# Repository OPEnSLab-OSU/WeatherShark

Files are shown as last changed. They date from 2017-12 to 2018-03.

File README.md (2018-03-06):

# WeatherShark

Links via Fusion to CAD files to 3D print

Hanging rod: http://a360.co/2F3G7Bz

Crossbar: http://a360.co/2F3G7Bz

Bearing Hanger: http://a360.co/2EYjwWZ

Fiber Clamp: http://a360.co/2FCrSVv - the new version of this needs to be refined a bit to get a good latch on the fiber

Ventilator with Turbine Rod: http://a360.co/2EYo6IR

Body + Bottom Plate: http://a360.co/2EXwTed

Note: Currently missing in the documentation: the WeatherShark board should have a 100 kOhm resistor from the RTC INT Pin to VCC.

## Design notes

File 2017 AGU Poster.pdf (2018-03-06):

# WeatherShark

# A light-weight weather station to swim through the skies

# Alex J Krejci¹ , Jose Manuel Lopez Alcala

1

# , Mitch Nelke

1

# , James Wagner

1

# , Chet Udell

1

# , Chad W Higgins

1

# , John S Selker

1

## 1 Department of Biological & Ecological Engineering, Oregon State University

Future
- Sell device
- Uploaded data for public access
- Use data for research

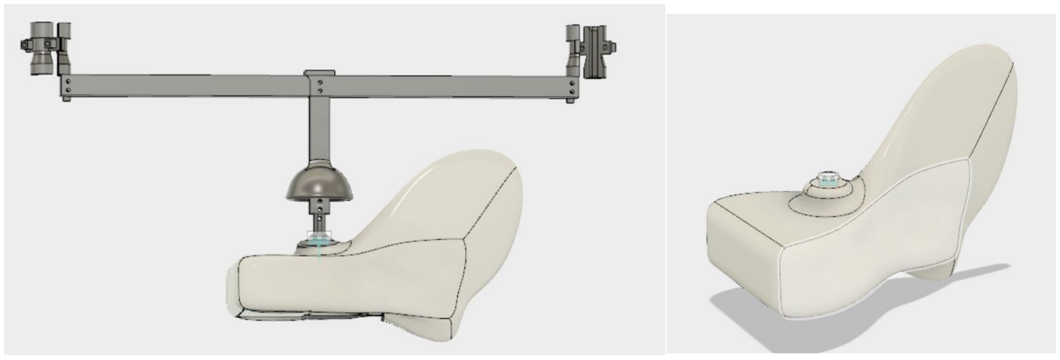
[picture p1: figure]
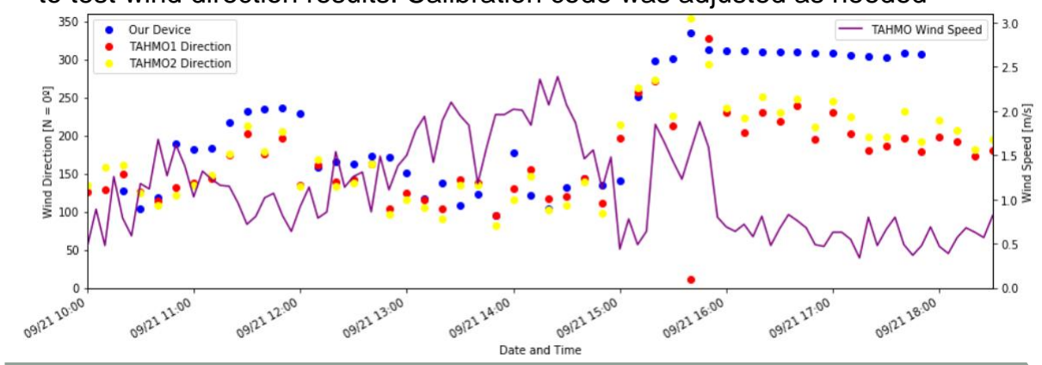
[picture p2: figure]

# Design Criteria

# Design Details – Version Gamma - Present

# Electronics

# Results – Version Beta - Past

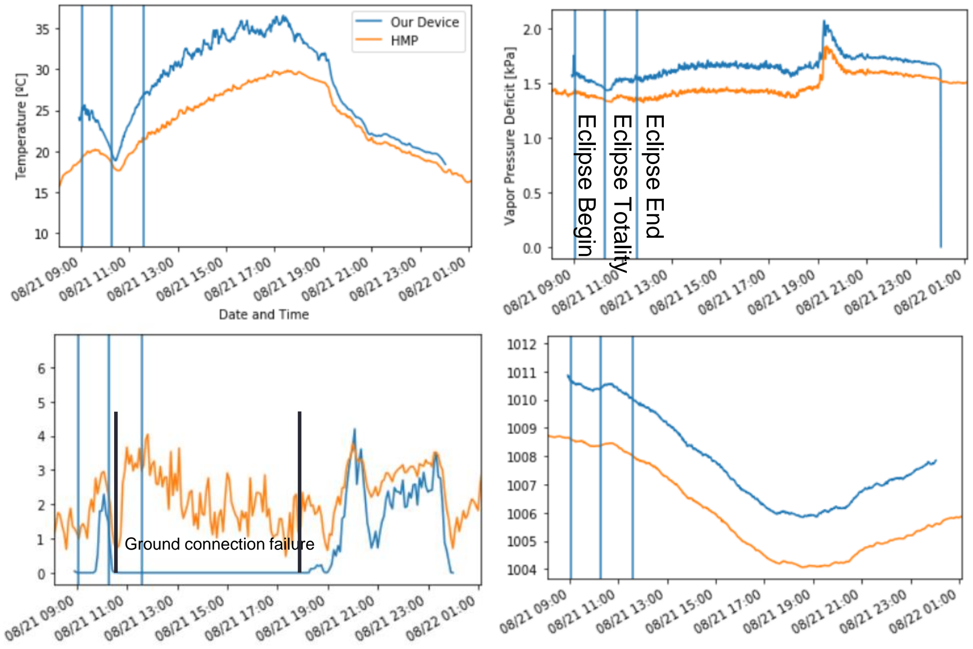
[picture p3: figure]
Eclipse End; Ground connection failure

Funding for this research was provided by NSF Earth Sciences division Instrumentation and Facilities program
The author would like to acknowledge the support of Jason Kelley, Hadi Al-Agele, and Thomas DeBell for useful discussions on design ideas.

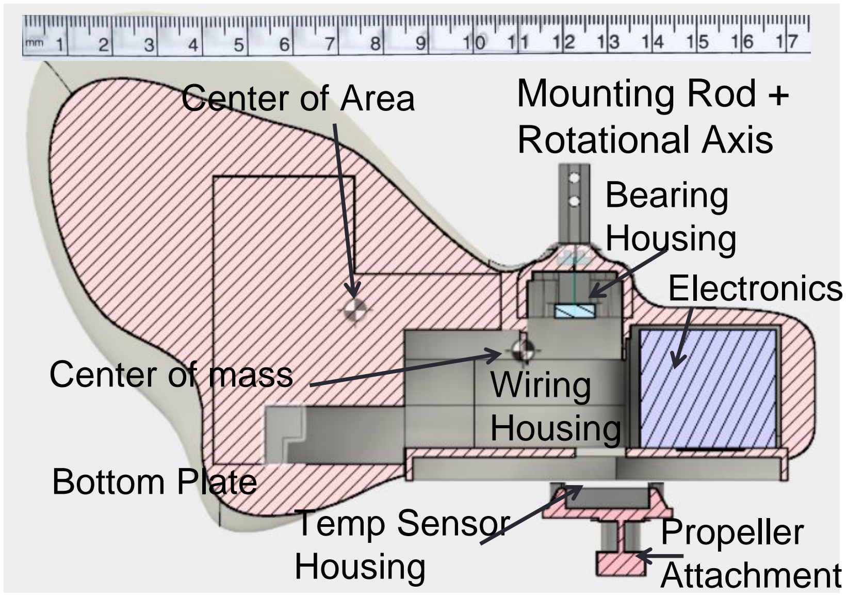
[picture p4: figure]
Electronics; Battery Compartment; Cross section of housing; Mounting Rod + Rotational Axis; Wiring Housing; Center of mass; Center of Area; Temp Sensor Housing; Propeller Attachment; Bearing Housing; Bottom Plate

# Version Gamma/Delta - Future

Beta
- Increased ventilation needed for temp sensor
- Wind direction at low speeds is poor – improve rotation capability Gamma
- Currently in testing phase – Beta problems are resolved
- Reliable sensor data should be available at this point
Delta
- Wireless communications, solar charging, and solar radiation sensing are a priority
- Rainfall - secondary objective.
Beyond
- Reduce form factor by building completely custom PCB
- Scalability using injection molding
- Retailing device for citizen science cloud data collection.

# ACKNOWLEDGMENTS

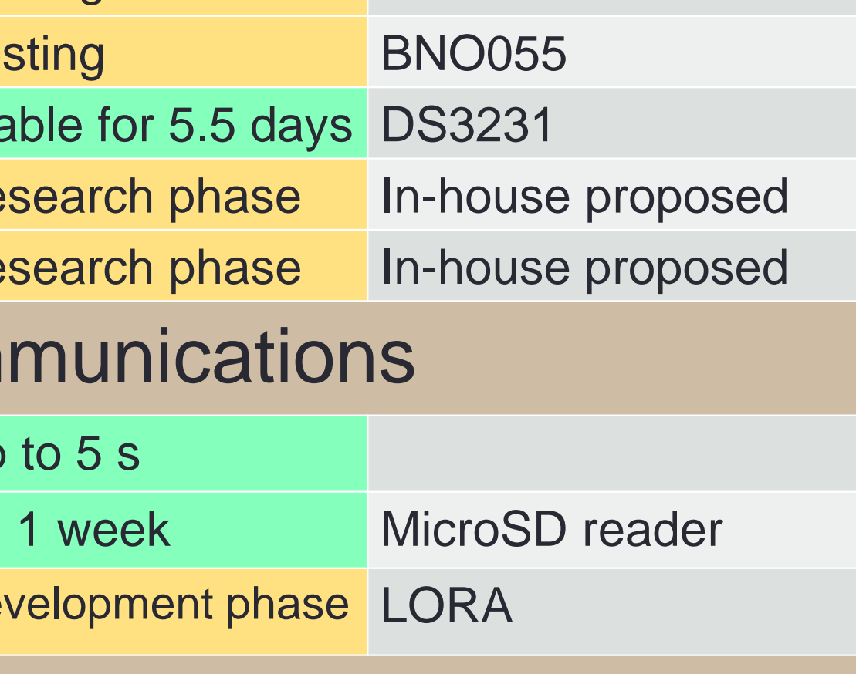
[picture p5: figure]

Left Dr Chet Udell and right Tom DeBell found an ideal POI
Battery Life | >12 hr | within range of the receiver through heavily wooded areas of 15 hr the HJ Andrews Forest. | 500 mAh Lithium Poly
Charging | No charging needed | Not Done | 80 mA solar panel

# Objective + Abstract

WeatherShark is an open-source, air-deployable weather station. The wind vane form factor has a complete electronics suite embedded including a light weight battery, data storage/communications, sensors, and microcontroller. The system is designed to be light weight (<200 g) and easily deployed (power on to deployment time ~2 minutes). These features, light weight and easily deployed, make it suitable for a variety of applications including aerial deployments (e.g. tethered weather balloon) as well as citizen science projects. The form factor is designed to be attractive while still scientifically functional

# Objective + Abstract

Desired | Achieved | Comments

## Measurement Capabilities

Pressure | ±1 hPa | ±0.12 hPa | BMP280
For as long as humans have tried to understand the natural world, they have attempted to Temperature take measurements to help deduce something significance about the world around them. | ±0.5 ºC | ±0.2 ºC | SHT31
Humidity However, these measurements have long come at the cost of individuals time, Capitol | ±2%RH | ±2%RH | SHT31
Wind Speed and available resources. These are often limited by the accuracy and availability of the | ±0.5 m/s | Testing | Built in house
equipment taking the measurements. The solution? An open sourced device with high Wind Direction | ±3º | Testing | BNO055
enough accuracy, at a low enough cost, that allows for extended observation in remote Time areas in near real time. The implications of such a technology allows researchers and | ±1 s | Stable for 5.5 days | DS3231
Solar Radiation scientists to form new data driven empirical models faster, and more cost efficiently then | Undefined | Research phase | In-house proposed
Rainfall ever before. | Undefined | Research phase | In-house proposed

## Data + Communications

Rate | Every 15 s | Up to 5 s
SD Storage | 1 week of data | >> 1 week | MicroSD reader
Wireless | Up to 1 km | Development phase | LORA

## Power Management

## Size

Weight | 100g | 175g | ½ body and ½ electronics
Length | <15 cm | 17 cm | 3D printed body

Microcontroller
- Featherwing M0 with SD card
- Can easily swap with Featherwing with LORA radio
- Built-in battery monitor, charging circuit, andjst connector

I2C devices
- SHT31 –temperature and humidity sensor
- BMP280 –pressure sensor
- BNO055 – 9 degree of freedom inertial motion unit Measures Pitch, Roll, and Yaw
- DS3231 – high precision real time clock

Digital pin devices
- IR transmitter and receiver w/ comparator circuit -measures wind speed
- RGB Neopixel status indicator

Referencing North
- Typical wind vane is mounted with stable reference to north
- Weather shark uses magnetic and gravitation fields to find north

# Housing and Mounting

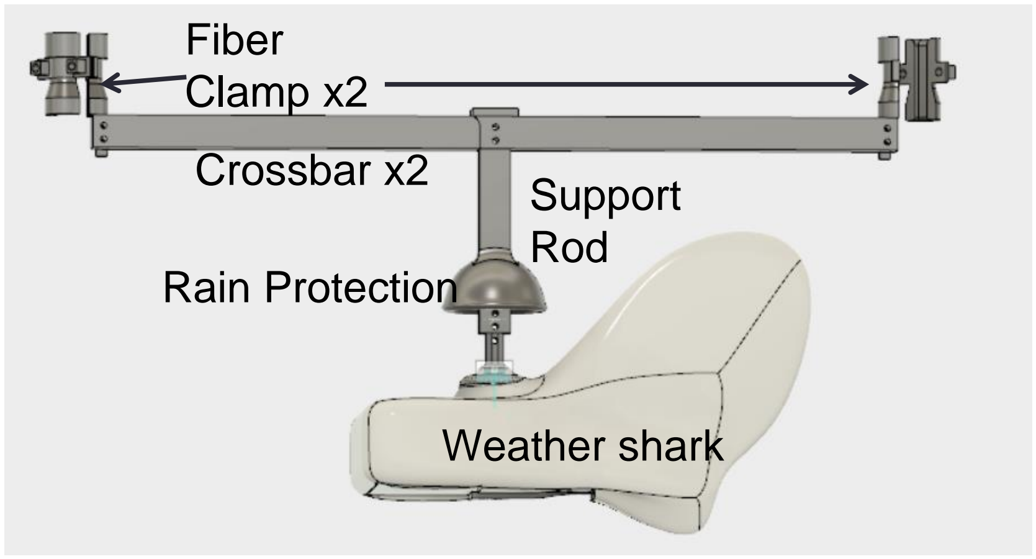
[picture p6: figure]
Fiber Clamp x2; Crossbar x2; Rain Protection; Support Rod; Weather shark

WeatherShark with fiber optic mounting attachments

- Center of area is behind center of mass so wind
pressure can will rotate
device
- Center of mass is behind the axis of rotation, this is compensated by
electronics weight
- Clamps grab fibers 1 mm
thick – other mounting
mechanisms are
available

Not shown – wind speed propeller and temperature sensor louver

# Eclipse Experiment

August 21

st – Eclipse passed over Corvallis Oregon. WeatherShark tested against Campbell Scientific HMP and Sonic Anemometer Eclipse Begin Eclipse Totality

# TAHMO Experiment

Summer 2017 – WeatherShark was collocated with TAHMO weather stations to test wind direction results. Calibration code was adjusted as needed

Current - Create weather station that is
- Low-cost
- Open-Source
- Deployable with weather
balloon

Lateral cross section of WeatherShark

To download related
files scan the QR Code

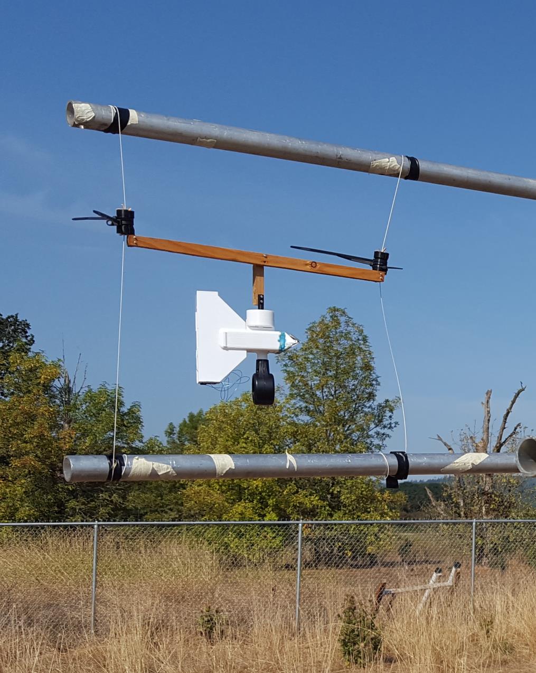
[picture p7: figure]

Beta version deployed in
the field

H121
241353

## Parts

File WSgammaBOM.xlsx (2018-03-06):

Bill of Materials | Site | Link | Price/unit | Units | Total Cost | Package Quantity | Packages Needed | Price per package | Total Price
Complete Parts
Digital Anemometer | Amazon | https://www.amazon.com/gp/product/B01LXX0GOZ/ref=ox_sc_act_title_2?smid=A1L1WUWYKZGTBQ&psc=1 | 17.99 | 1 | 17.99 | 1 | 7 | 17.99 | 125.93
Breakout Modules
SHT31D Breakout | Adafruit | https://www.adafruit.com/product/2857 | 13.95 | 1 | 13.95 | 1 | 7 | 13.95 | 97.65
BMP280 | Amazon | https://www.amazon.com/Adafruit-BMP280-Barometric-Pressure-Altitude/dp/B013W0RR6Y | 10.4 | 1 | 10.4 | 1 | 7 | 10.4 | 72.8
DS3231 | Adafruit | https://www.adafruit.com/product/3013 | 13.95 | 1 | 13.95 | 1 | 7 | 13.95 | 97.65
BNO055 | Adafruit | https://www.adafruit.com/product/2472 | 34.95 | 1 | 34.95 | 1 | 7 | 34.95 | 244.65
Neopixel | Adafruit | https://www.adafruit.com/product/1312 | 1.9875 | 1 | 1.9875 | 4 | 2 | 7.95 | 15.9
Featherwing M0+SD | Adafruit | https://www.adafruit.com/product/2796 | 19.95 | 1 | 19.95 | 1 | 7 | 19.95 | 139.65
Lipo Charger | Adafruit | https://www.adafruit.com/product/1304 | 5.95 | 1 | 5.95 | 1 | 7 | 5.95 | 41.65
Connections
Molex 6-pin connector | Spark fun | https://www.sparkfun.com/products/9922 | 1.95 | 1 | 1.95 | 1 | 7 | 1.95 | 13.65
Male Headers | Adafruit | https://www.adafruit.com/product/2671 | 0.59 | 1 | 0.59 | 5 | 2 | 2.95 | 5.9
Low Profile female headers | Adafruit | https://www.adafruit.com/product/3008 | 1.59 | 1 | 1.59 | 5 | 2 | 7.95 | 15.9
Male 6 pin Connector Parts
22 gauage Red,Black,Gr-een,Yellow,Blue, Orange Wire | Opens lab |  |  | 6
male connectors | Opens lab |  |  | 6
6 pin connector cartridge | Opens lab |  |  | 1
Hardware
M2 threaded inserts | McMaster | https://www.mcmaster.com/#threaded-inserts/=1b5qzxh | 0.1044 | 3 | 0.3132 | 100 | 1 | 10.44 | 10.44
M2 ~25 mm | McMaster | https://www.mcmaster.com/#standard-rounded-head-screws/=1b5r1ya | 0.2632 | 4 | 1.0528 | 25 | 2 | 6.58 | 13.16
M2 ~12mm | McMaster | https://www.mcmaster.com/#standard-rounded-head-screws/=1b5r1ya | 0.0616 | 3 | 0.1848 | 100 | 1 | 6.16 | 6.16
M2 ~6mm | McMaster
Fidget Spinner Bearing | Amazon | https://www.amazon.com/Holody-FID-10-Spinner-Bearings-Replacement/dp/B072JZ1M5N?s=industrial | 0.899 | 1 | 0.899 | 10 | 1 | 8.99 | 8.99
Sticky Tack | Amazon | https://www.amazon.com/Loctite-Fun-Tak-Mounting-2-Ounce-1087306/dp/B001F57ZPW?s=industrial | 4.12 | 1 | 4.12 | 1 | 7 | 4.12 | 28.84
3D printing
Main Body | Opens |  | 0.1 | 70 | 7 |  |  |  | 49
Bottom Plate | Opens |  | 0.1 | 10 | 1 |  |  |  | 7
Axle | Opens |  | 0.1 | 5 | 0.5 |  |  |  | 3.5
Rain Cover Rod | Opens |  | 0.1 | 20 | 2 |  |  |  | 14
Fiber Attachment pieces | Opens |  | 0.1 | 40 | 4 |  |  |  | 28
Electronics
100 kΩ Resistor | Mouser | https://www.mouser.com/productdetail/yageo/cfr25sjt-52-100k | 0.1 | 2 | 0.2 | 1 | 14 | 0.1 | 1.4
330 Ω Resistor | Mouser | https://www.mouser.com/ProductDetail/Yageo/CFR-25JT-52-330R/?qs=KUIzHt%2fe91mWpUNK8rcuyw%3d%3d | 0.1 | 2 | 0.2 | 1 | 14 | 0.1 | 1.4
120k Ω Resistor | Mouser | https://www.mouser.com/ProductDetail/Yageo/CFR25SJT-52-120K/?qs=gt1LBUVyoHmr7KgMfs54IQ%3d%3d | 0.1 | 1 | 0.1 | 1 | 7 | 0.1 | 0.7
3.9 MΩ Resistor | Mouser | https://www.mouser.com/ProductDetail/Yageo/CFR-25JB-52-3M9/?qs=oypCK0zG324hndkFPn0Tzw%3d%3d | 0.1 | 1 | 0.1 | 1 | 7 | 0.1 | 0.7
LM358 Op Amp | Mouser | https://www.mouser.com/productdetail/on-semiconductor-fairchild/lm358an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 | 0.46 | 1 | 0.46 | 1 | 7 | 0.46 | 3.22
WeatherShark Board | OshPark | https://oshpark.com/ | 9.133333333 | 1 | 9.133333333 | 1 | 7 | 9.133333333 | 63.93333333
EvapoShark Board | OshPark | https://oshpark.com/ | 10 | 1 | 10 | 1 | 7 | 10 | 70
Lipo Battery 500 mAh | Adafruit | https://www.adafruit.com/product/1578 | 7.95 | 1 | 7.95 | 1 | 7 | 7.95 | 55.65
SD Card 8 GB | Amazon | https://www.amazon.com/PACK-SanDisk-MicroSD-SDSDQAB-008G-Packaging/dp/B00MHZ6ZJQ?s=pc | 6.256 | 1 | 6.256 | 5 | 2 | 31.28 | 62.56
36"x1/8" Steel Rod | Amazon | https://www.amazon.com/dp/B0050RI8OI/ref=biss_dp_t_asn | 2.8325 | 1 | 2.8325 | 4 | 2 | 11.33 | 22.66
Total/device |  |  |  |  | 172.4706333
Number of Devices |  |  |  |  | 7
Subtotal Devices |  |  |  |  | 1207.294433 |  |  |  | 1322.643333
Single Items
USB Hub | Amazon | https://www.amazon.com/Sedna-Port-USB-Internal-Floppy/dp/B00V2FIOK0?s=industrial | 27.6 | 1 | 27.6 | 1
Wrapping Wire | Amazon | https://www.amazon.com/Breadboard-B-30-1000-Plated-Copper-Wrapping/dp/B008AGUAII?s=industrial | 11.92 | 1 | 11.92 | 1
Subtotal Single Items |  |  |  |  | 39.52
Total |  |  |  |  | 1246.814433 |  |  |  | 1362.163333
 |  |  |  |  | Total order price assuming I can order 1 by 1 |  |  |  | Total order price with the packaging neeed

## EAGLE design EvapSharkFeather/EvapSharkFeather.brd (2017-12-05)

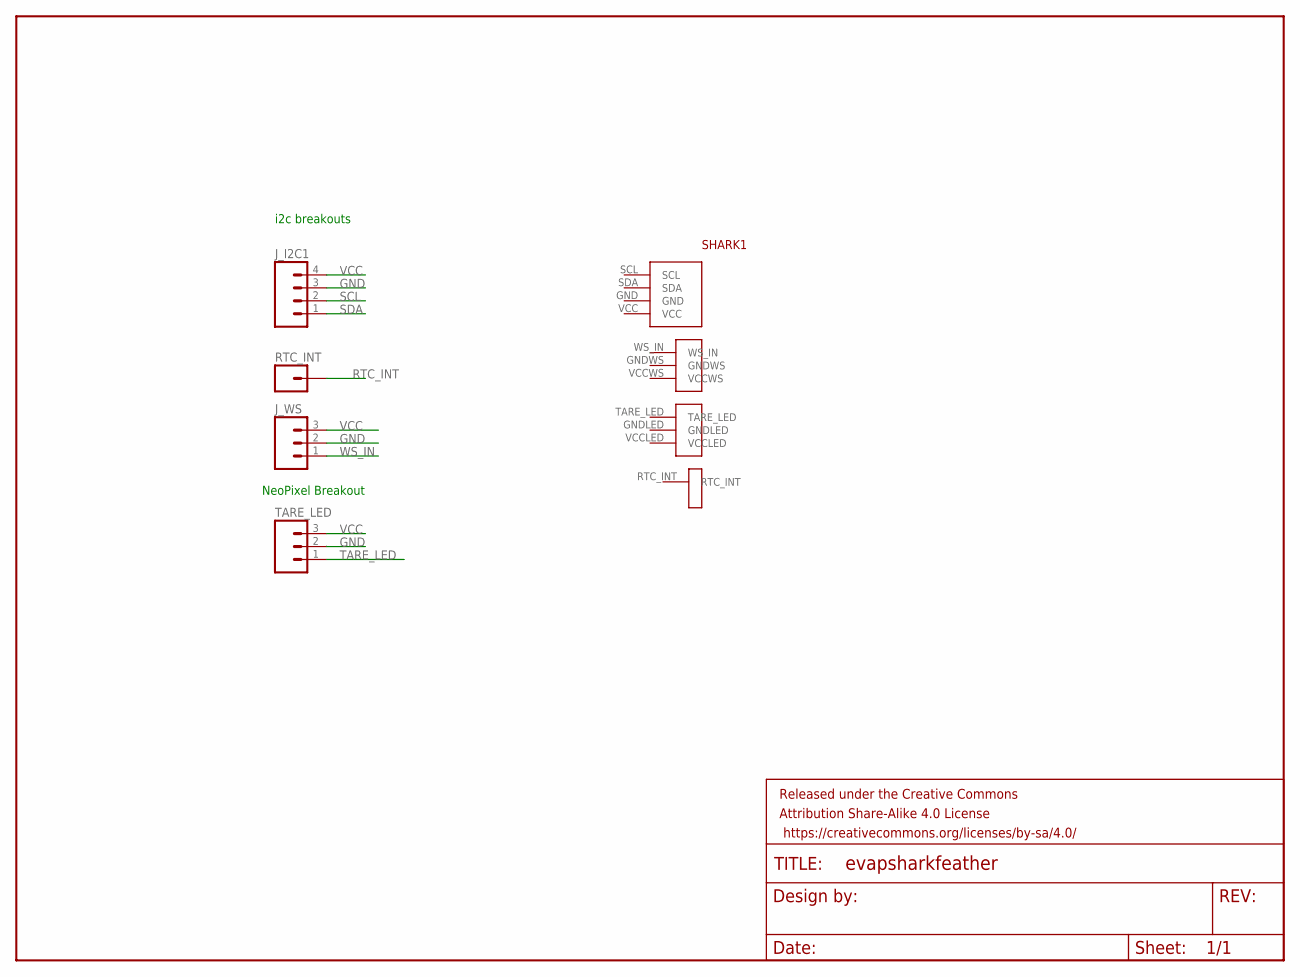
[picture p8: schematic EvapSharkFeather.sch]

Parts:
FRAME1: FRAME-LETTER; CREATIVE_COMMONS
J_I2C1: M04PTH; 1X04
J_WS: M03PTH; 1X03
RTC_INT: M01PTH; 1X01
SHARK1: EVAPSHARK
TARE_LED: M03PTH; 1X03

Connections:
GND: J_I2C1.3, J_WS.2, SHARK1.GND, TARE_LED.2
GNDLED: SHARK1.GNDLED
GNDWS: SHARK1.GNDWS
RTC_INT: RTC_INT.1
SCL: J_I2C1.2
SDA: J_I2C1.1
TARE_LED: TARE_LED.1
VCC: J_I2C1.4, J_WS.3, SHARK1.VCC, TARE_LED.3
VCCLED: SHARK1.VCCLED
VCCWS: SHARK1.VCCWS
WS_IN: J_WS.1

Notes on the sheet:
i2c breakouts
NeoPixel Breakout

Board: 2 copper layers, 17 parts (0 on the bottom side), 2 nets, no tracks yet.

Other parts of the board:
BMP1: ADAFRUITBMP280
BNO1: ADAFRUITBNO055
DS1: ADAFRUITDS3231
J1: MOLEX-1X6
NEO1: ADAFRUITNEOPIXELBREAKOUT
R1, R2, R3, R4, R5: AXIAL-0.3
U1: DIP08-KIT

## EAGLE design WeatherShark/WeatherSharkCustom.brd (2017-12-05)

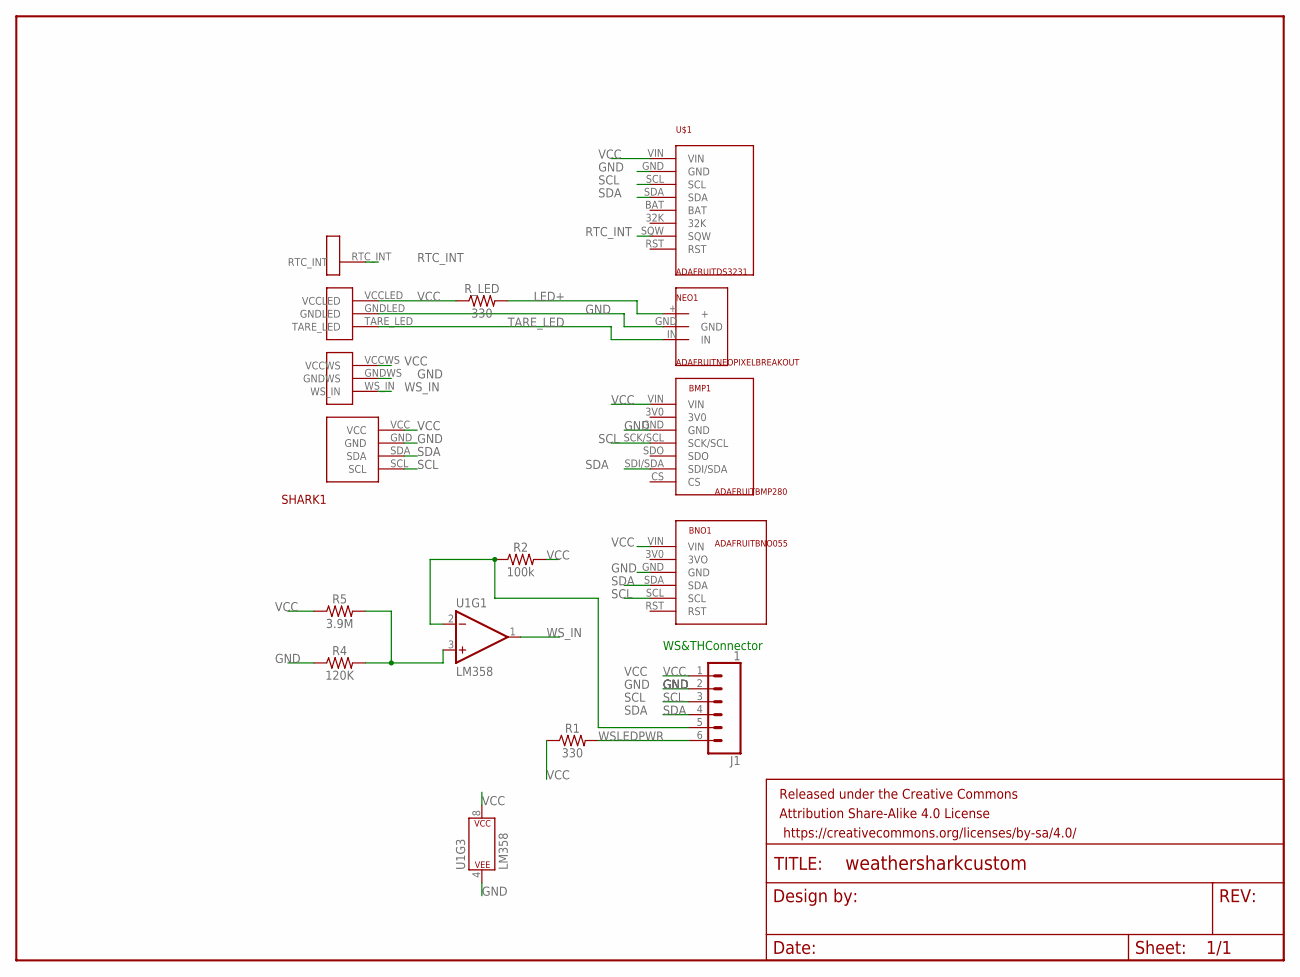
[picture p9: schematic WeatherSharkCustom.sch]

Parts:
BMP1: ADAFRUITBMP280
BNO1: ADAFRUITBNO055
FRAME1: FRAME-LETTER; CREATIVE_COMMONS
J1: 1; MOLEX-1X6
NEO1: ADAFRUITNEOPIXELBREAKOUT
R1: 330; AXIAL-0.3
R2: 100k; AXIAL-0.3
R4: 120K; AXIAL-0.3
R5: 3.9M; AXIAL-0.3
R_LED: 330; AXIAL-0.3
SHARK1: EVAPSHARK
U1: LM358; DIP08-KIT
U$1: ADAFRUITDS3231

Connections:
COMP: R4.P$2 (2), R5.P$2 (2), U1.3 (+IN)
GND: BMP1.GND, BNO1.GND, J1.2, NEO1.GND, R4.P$1 (1), SHARK1.GND, SHARK1.GNDLED, SHARK1.GNDWS, U1.4 (P$V-), U$1.GND
LED+: NEO1.+, R_LED.P$2 (2)
RTC_INT: SHARK1.RTC_INT, U$1.SQW
SCL: BMP1.SCK/SCL, BNO1.SCL, J1.3, SHARK1.SCL, U$1.SCL
SDA: BMP1.SDI/SDA, BNO1.SDA, J1.4, SHARK1.SDA, U$1.SDA
TARE_LED: NEO1.IN, SHARK1.TARE_LED
VCC: BMP1.VIN, BNO1.VIN, J1.1, R1.P$1 (1), R2.P$2 (2), R5.P$1 (1), R_LED.P$1 (1), SHARK1.VCC, SHARK1.VCCLED, SHARK1.VCCWS, U1.8 (P$V+), U$1.VIN
WSLEDPWR: J1.6, R1.P$2 (2)
WSSIGNAL: J1.5, R2.P$1 (1), U1.2 (-IN)
WS_IN: SHARK1.WS_IN, U1.1 (OUT)

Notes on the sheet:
WS&THConnector

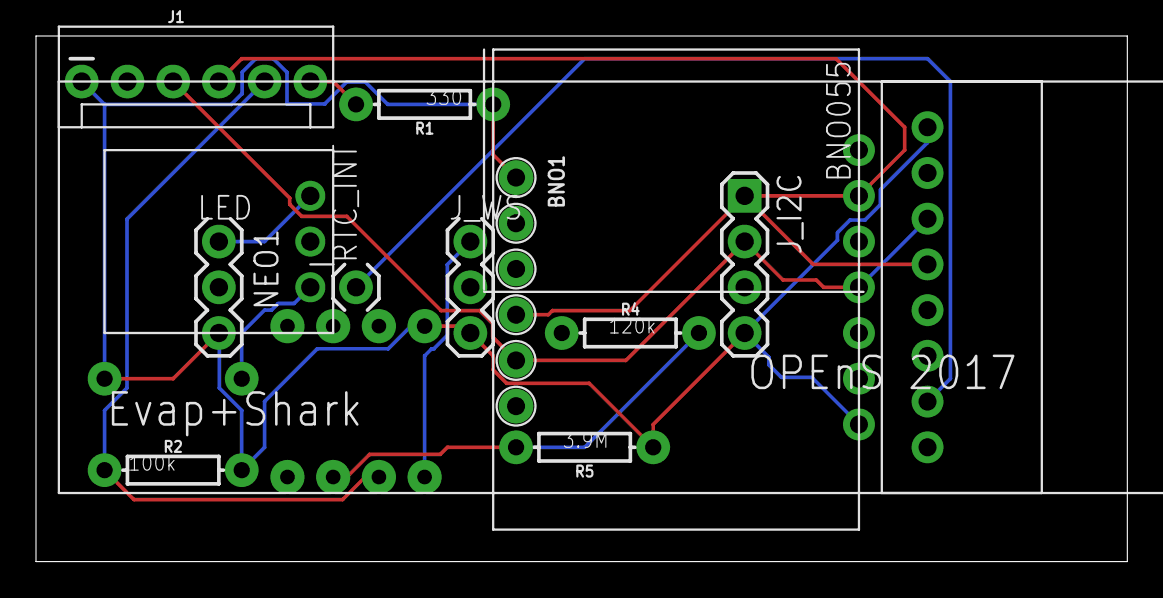
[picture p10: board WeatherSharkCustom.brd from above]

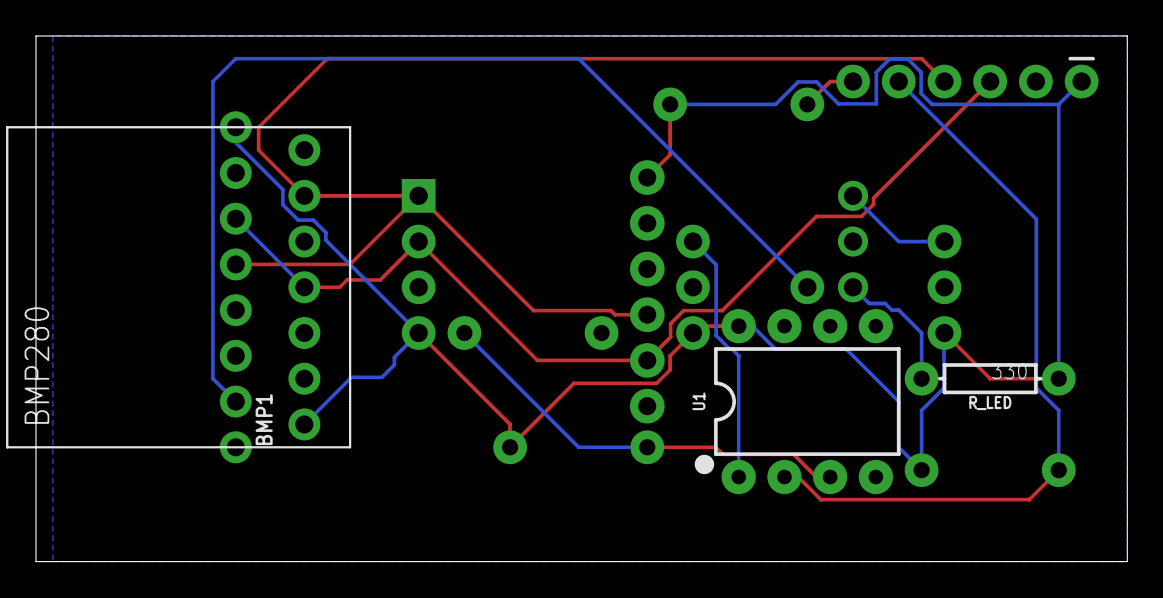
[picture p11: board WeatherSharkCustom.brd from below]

Board: 2 copper layers, 60.6 x 29.2 mm, 13 parts (3 on the bottom side), 11 nets.

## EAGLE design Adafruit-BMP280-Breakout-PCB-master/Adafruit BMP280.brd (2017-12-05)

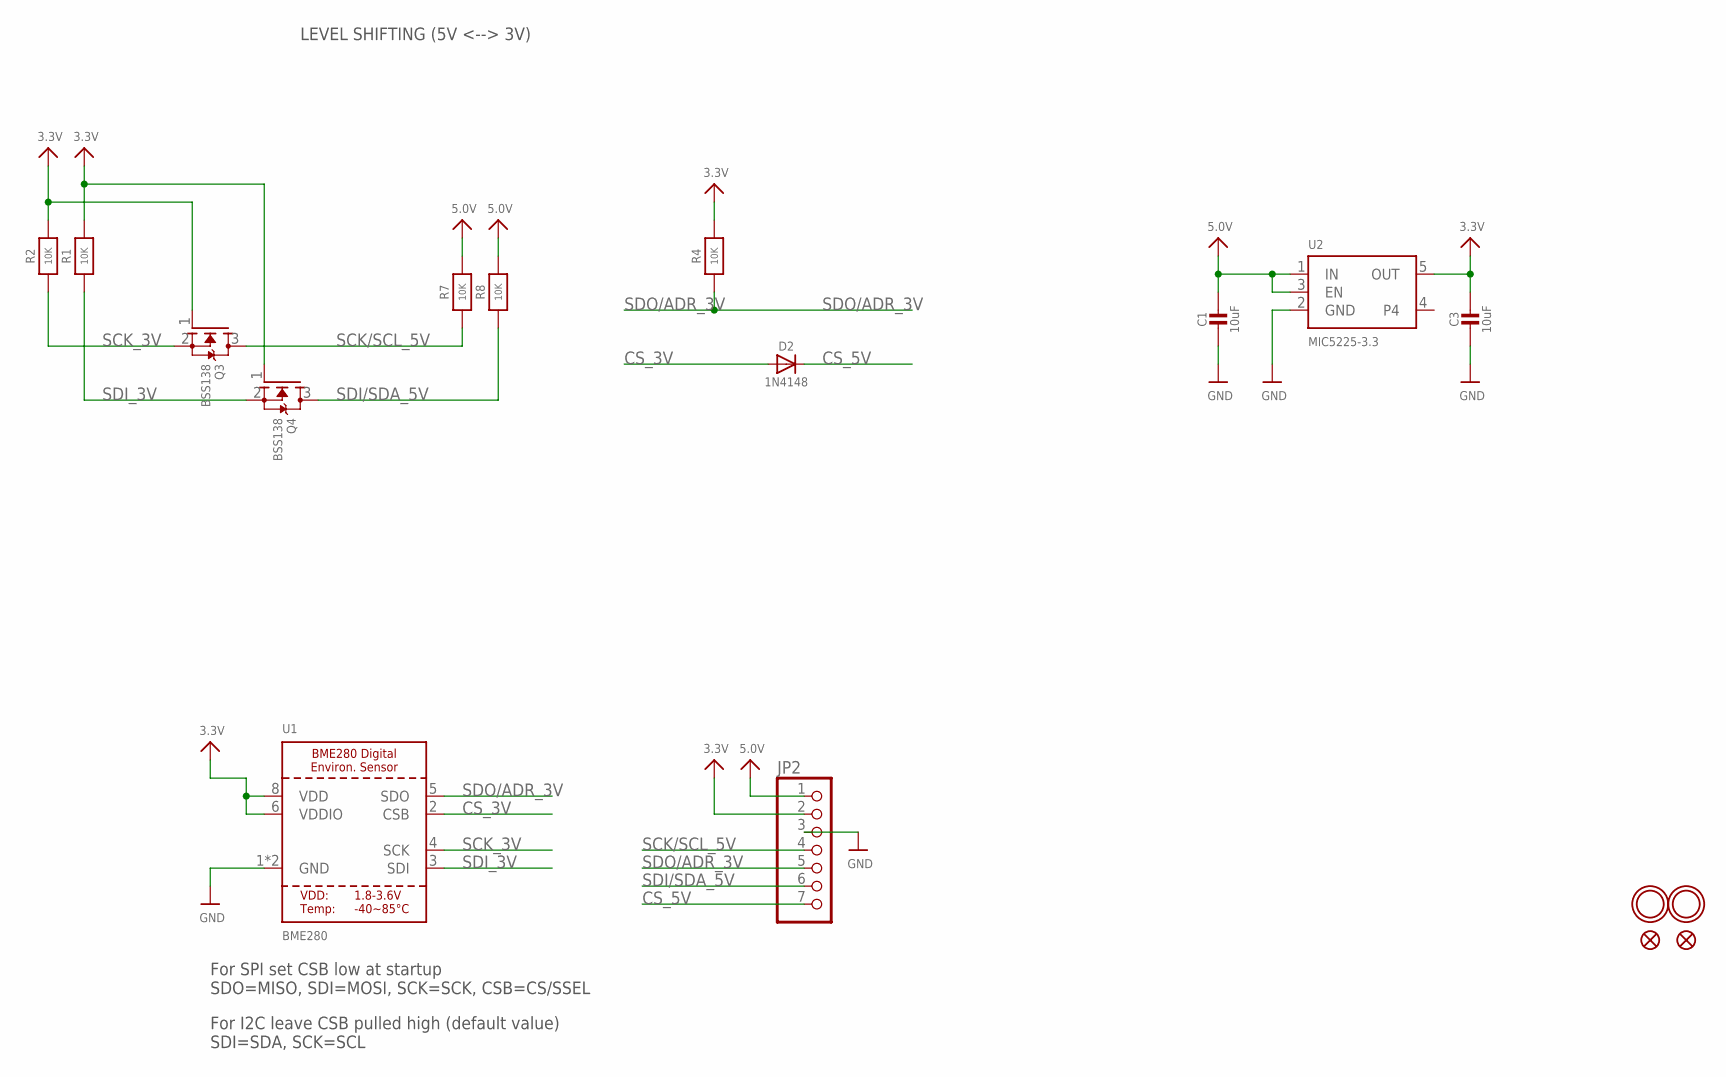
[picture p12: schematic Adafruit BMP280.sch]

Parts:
C1, C3: 10uF; 0805-NO
D2: 1N4148; SOD-323
JP2: HEADER-1X770MIL; 1X07_ROUND_70
Q3, Q4: BSS138; SOT23-WIDE
R1, R2, R7, R8: 10K; 0805-NO
R4: 10K; _0805MP
U1: BME280
U2: MIC5225-3.3; SOT23-5
U$5, U$15: FIDUCIAL""; FIDUCIAL_1MM
U$7, U$8: MOUNTINGHOLE2.0; MOUNTINGHOLE_2.0_PLATED

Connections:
3.3V: C3.1, JP2.2, Q3.1 (G), Q4.1 (G), R1.2, R2.2, R4.2, U1.6 (VDDIO), U1.8 (VDD), U2.5 (OUT)
5.0V: C1.1, JP2.1, R7.2, R8.2, U2.1 (IN), U2.3 (EN)
CS_3V: D2.A, U1.2 (CSB)
CS_5V: D2.C, JP2.7
GND: C1.2, C3.2, JP2.3, U1.1 (GND), U1.7 (GND), U2.2 (GND)
SCK/SCL_5V: JP2.4, Q3.3 (D), R7.1
SCK_3V: Q3.2 (S), R2.1, U1.4 (SCK)
SDI/SDA_5V: JP2.6, Q4.3 (D), R8.1
SDI_3V: Q4.2 (S), R1.1, U1.3 (SDI)
SDO/ADR_3V: JP2.5, R4.1, U1.5 (SDO)

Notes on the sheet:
For SPI set CSB low at startup SDO=MISO, SDI=MOSI, SCK=SCK, CSB=CS/SSEL
For I2C leave CSB pulled high (default value) SDI=SDA, SCK=SCL
LEVEL SHIFTING (5V <--> 3V)

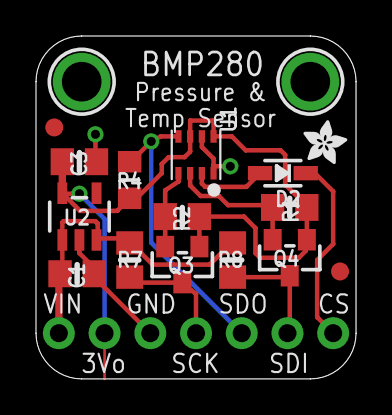
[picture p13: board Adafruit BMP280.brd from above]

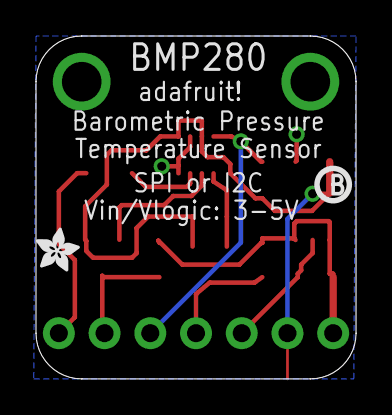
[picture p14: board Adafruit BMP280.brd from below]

Board: 2 copper layers, 17.8 x 19.1 mm, 20 parts (2 on the bottom side), 10 nets.

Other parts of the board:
U$2, U$6: ADAFRUIT_2.5MM
U$20: PCBFEAT-REV-040

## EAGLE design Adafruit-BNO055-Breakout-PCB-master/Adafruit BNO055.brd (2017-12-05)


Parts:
C1, C2: 22pF; 0805-NO
C3: 0.1uF; 0805-NO
C4: 0.1uF; 0805_10MGAP
C5: 10uF; 0805-NO
C6: 10uF; 0805_10MGAP
D1: 1n4148; SOD-323
FID1, FID2: FIDUCIAL""; FIDUCIAL_1MM
JP1: HEADER-1X676MIL; 1X06_ROUND_76
JP2: HEADER-1X476MIL; 1X04_ROUND_76
Q1, Q2: BSS138; SOT23-WIDE
R3, R4, R5, R6, R7, R10: 10K; 0805-NO
R8, R9: 10K; _0805MP
U1: MIC5225-3.3; SOT23-5
U$2: BNO055
U$29, U$30, U$31, U$32: MOUNTINGHOLE2.5_THICK; MOUNTINGHOLE_2.5_PLATED_THICK
Y1: 32.768kHz; CRYSTAL_8X3.8

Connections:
3.3V: C4.2, C6.1, JP1.2, Q1.1 (G), Q2.1 (G), R6.2, R7.2, R10.2, U1.5 (OUT), U$2.3 (VDD), U$2.4 (NBOOT_LOAD_PIN), U$2.28 (VDDIO)
5.0V: C5.1, JP1.1, R8.2, R9.2, U1.1 (IN), U1.3 (EN)
GND: C1.1, C2.1, C3.1, C4.1, C5.2, C6.2, JP1.3, R3.2, R4.2, R5.2, U1.2 (GND), U$2.2 (GND), U$2.10 (PIN10(GND)), U$2.15 (PIN15(GND)), U$2.16 (PIN16(GND)), U$2.18 (COM2(GND)), U$2.25 (GND)
I2CADDR_3V: JP2.4, R5.1, U$2.17 (COM3/I2C_ADDR)
INT_3V: JP2.3, U$2.14 (INT)
unnamed: C1.2, U$2.27 (XIN32), Y1.P$4 (2)
unnamed: C2.2, U$2.26 (XOUT32), Y1.P$1 (1)
unnamed: C3.2, U$2.9 (CAP)
NRESET_3V: D1.A, R10.1, U$2.11 (NRESET)
PS0_3V: JP2.1, R3.1, U$2.6 (PS0)
PS1_3V: JP2.2, R4.1, U$2.5 (PS1)
RST_5V: D1.C, JP1.6
SCL_3V: Q2.2 (S), R7.1, U$2.19 (COM1/SCL/RX)
SCL_5V: JP1.5, Q2.3 (D), R9.1
SDA_3V: Q1.2 (S), R6.1, U$2.20 (COM0/SDA/TX)
SDA_5V: JP1.4, Q1.3 (D), R8.1



Board: 2 copper layers, 26.7 x 20.3 mm, 31 parts (2 on the bottom side), 16 nets.

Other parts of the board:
U$3: PCBFEAT-REV-040
U$28: ADAFRUIT_TEXT_20MM
U$33: ADAFRUIT_2.5MM

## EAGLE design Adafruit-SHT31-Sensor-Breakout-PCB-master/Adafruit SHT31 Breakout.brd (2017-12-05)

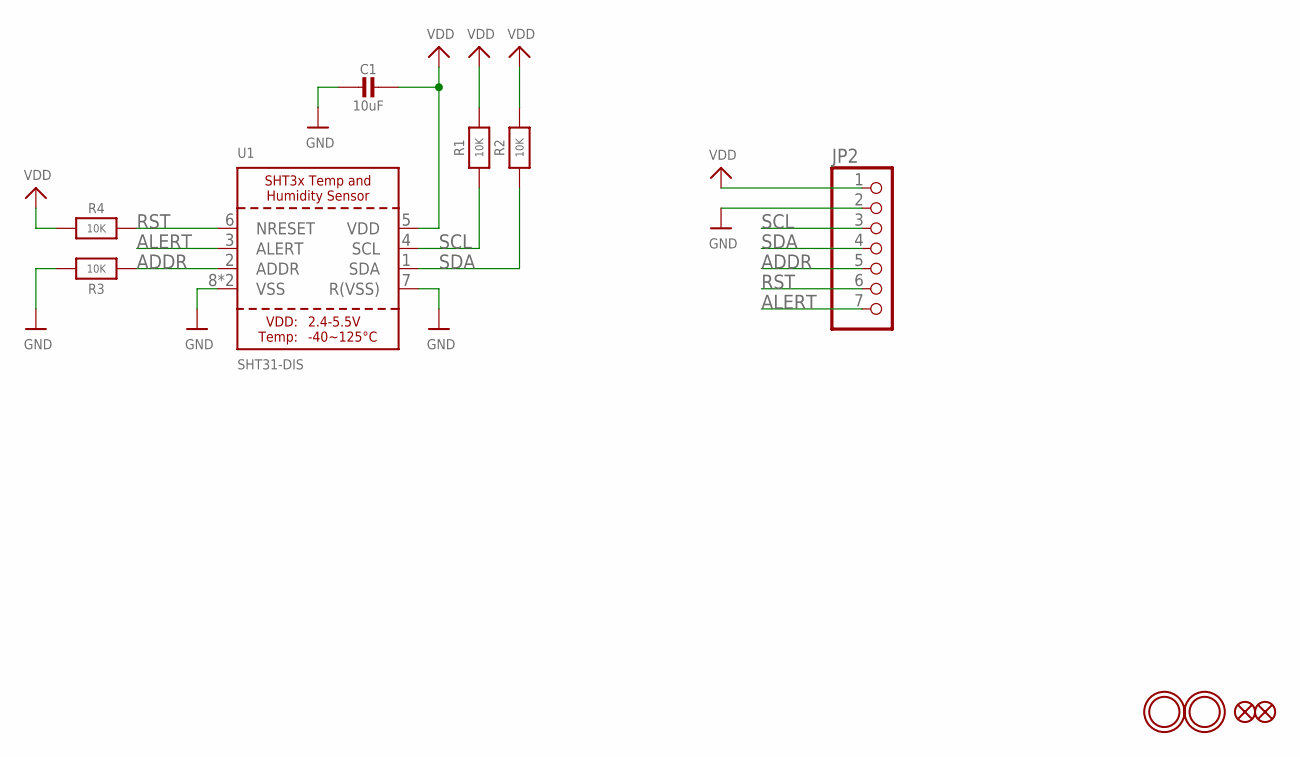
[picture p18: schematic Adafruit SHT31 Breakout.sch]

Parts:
C1: 10uF; 0805-NO
FID2, FID3: FIDUCIAL""; FIDUCIAL_1MM
JP2: HEADER-1X770MIL; 1X07_ROUND_70
R1, R2, R4: 10K; 0805-NO
R3: 10K; _0805MP
U1: SHT31-DIS; SHT3X
U$1, U$2: MOUNTINGHOLE2.5; MOUNTINGHOLE_2.5_PLATED

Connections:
ADDR: JP2.5, R3.1, U1.2 (ADDR)
ALERT: JP2.7, U1.3 (ALERT)
GND: C1.2, JP2.2, R3.2, U1.7 (R(VSS)), U1.8 (VSS), U1.THERMAL (VSS)
RST: JP2.6, R4.2, U1.6 (NRESET)
SCL: JP2.3, R1.1, U1.4 (SCL)
SDA: JP2.4, R2.1, U1.1 (SDA)
VDD: C1.1, JP2.1, R1.2, R2.2, R4.1, U1.5 (VDD)

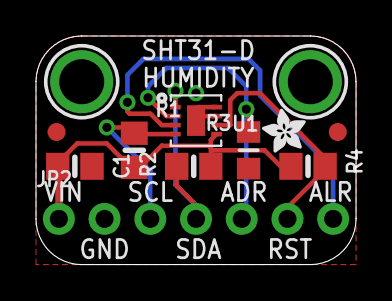
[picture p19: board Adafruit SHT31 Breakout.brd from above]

Board: 2 copper layers, 17.8 x 12.7 mm, 13 parts (1 on the bottom side), 7 nets.

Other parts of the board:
U$11: PCBFEAT-REV-040
U$13: ADAFRUIT_2.5MM

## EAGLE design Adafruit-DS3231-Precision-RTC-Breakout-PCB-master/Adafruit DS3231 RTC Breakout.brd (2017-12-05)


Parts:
B1: CR1220
C1: 1uF; 0805-NO
FID1, FID2, FID3, FID4: FIDUCIAL""; FIDUCIAL_1MM
IC1: DS3231/SO; SO16W
JP1: HEADER-1X870MIL; 1X08_ROUND_70
R1, R2: 10K; 0805-NO
U$6, U$7: MOUNTINGHOLE2.5; MOUNTINGHOLE_2.5_PLATED

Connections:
3.3V: C1.2, IC1.2 (VCC), JP1.1, R1.1, R2.1
32KHZ: IC1.1 (32KHZ), JP1.6
!RTC_RST: IC1.4 (/RST), JP1.8
GND: B1.-, C1.1, IC1.13 (GND), JP1.2
SCL: IC1.16 (SCL), JP1.3, R2.2
SDA: IC1.15 (SDA), JP1.4, R1.2
SQW: IC1.3 (SQW/INT), JP1.7
VBAT: B1.+$1 (+), IC1.14 (VBAT), JP1.5



Board: 2 copper layers, 22.9 x 17.8 mm, 14 parts (3 on the bottom side), 8 nets.

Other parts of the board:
U$8: ADAFRUIT_3.5MM
U$9: PCBFEAT-REV-040

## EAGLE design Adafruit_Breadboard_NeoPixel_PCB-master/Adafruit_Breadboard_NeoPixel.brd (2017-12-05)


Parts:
C1: 1uF; C0603K
JP1, JP2: PINHD-1X3CB; 1X03-CLEANBIG
LED1: WS28115050
R1: 1.0K; R0603
R2, R3: 22; R0603

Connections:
GND: C1.2, JP1.2, JP2.2, LED1.VSS (GND)
IN: JP1.1, R3.2
unnamed: LED1.DO, R2.1
unnamed: LED1.DI, R3.1
unnamed: C1.1, LED1.VDD, R1.1
OUT: JP2.3, R2.2
VDD: JP1.3, JP2.1, LED1.LEDVDD, R1.2


Board: 2 copper layers, 12.7 x 10.2 mm, 8 parts (1 on the bottom side), 7 nets.

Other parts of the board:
U$1: ADAFRUIT_2.5MM

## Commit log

2017-12-05 Add existing file
    [Adafruit BMP280.brd, Adafruit BMP280.sch, Adafruit BNO055.brd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]
2018-03-06 Added links for CAD files for parts to 3D print
    Also added note about missing resistor
2018-03-06 Added BOM and AGU poster
    [WSgammaBOM.xlsx]

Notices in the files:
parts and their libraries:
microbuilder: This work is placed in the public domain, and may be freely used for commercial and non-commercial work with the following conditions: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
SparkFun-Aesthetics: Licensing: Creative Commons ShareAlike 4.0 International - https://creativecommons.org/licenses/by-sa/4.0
